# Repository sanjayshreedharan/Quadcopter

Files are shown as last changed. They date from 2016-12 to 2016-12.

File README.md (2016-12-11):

# Quadcopter
An Indigenous Low cost Autopilot System for a Quadcopter using Arduino UNO/ FPGA.
 
This project endeavours to design a low cost indigenous auto-pilot system for a quadcopter using the Arduino UNO. This tutorial majorly deals only with the design and deployment of the autopilot system and we assume that you already have the frame, motors, ESC’s and the Lipo Batteries in place. This project also includes the PCB schematic on which our firmware is run.  

# Video

DEMO Video (http://www.youtube.com/watch?v=Ulz9EfYzbyA)

# Deployment Instructions
The frame can either be designed or it can be bought. For speedy development, if you don't have much time in your hands I would suggest to go with buying one. 

We obviously designed our own frame and since frame design and construction as such is a huge task, I would follow up with a tutorial for those of you who wish to design your own frames.

After the frame is ready, the next would be to get the motors, ESC’s, propellers and the power supply in place.The rating of the motors, ESC’s and power supply depends on the size of the frame and the pay-load capacity of the quadcopter. 

For autopilot, a 9DOF IMU (Inertial measurements unit), which consists of an accelerometer, gyroscope and a magnetometer is required. For wireless communication, Bluetooth or RC would do the job. We used the Bluetooth as we would be able to keep a watch on the state of the quadcopter through the serial monitor and also send commands. If flying low-heights and debugging is your requirement, go with bluetooth. For those of you who wish to fly great heights, use a RC module. 

The MPU6050 (6 DOF IMU with accelerometer and gyroscope) and HMC5883L(Magnetometer) was combined to give the quadcopter 9 degrees of freedom. The HC-06 module was used as bluetooth.

A custom Arduino UNO shield was designed for the purpose of a quadcopter. The schematic and the board design is available. So, if you know know how to make a PCB, you can make the shield with the MPU6050, HMC5883L and HC-06 on it and it would fit perfectly on top of the UNO.  

If making PCB is not your piece of cake, I would suggest you to connect the sensors with jumper wires. Make sure the connections, that you have made are reliable, if they are not this might pose a serious problem when the quadcopter is on the go.

After this is done, download the code and fuse it into your Arduino UNO.

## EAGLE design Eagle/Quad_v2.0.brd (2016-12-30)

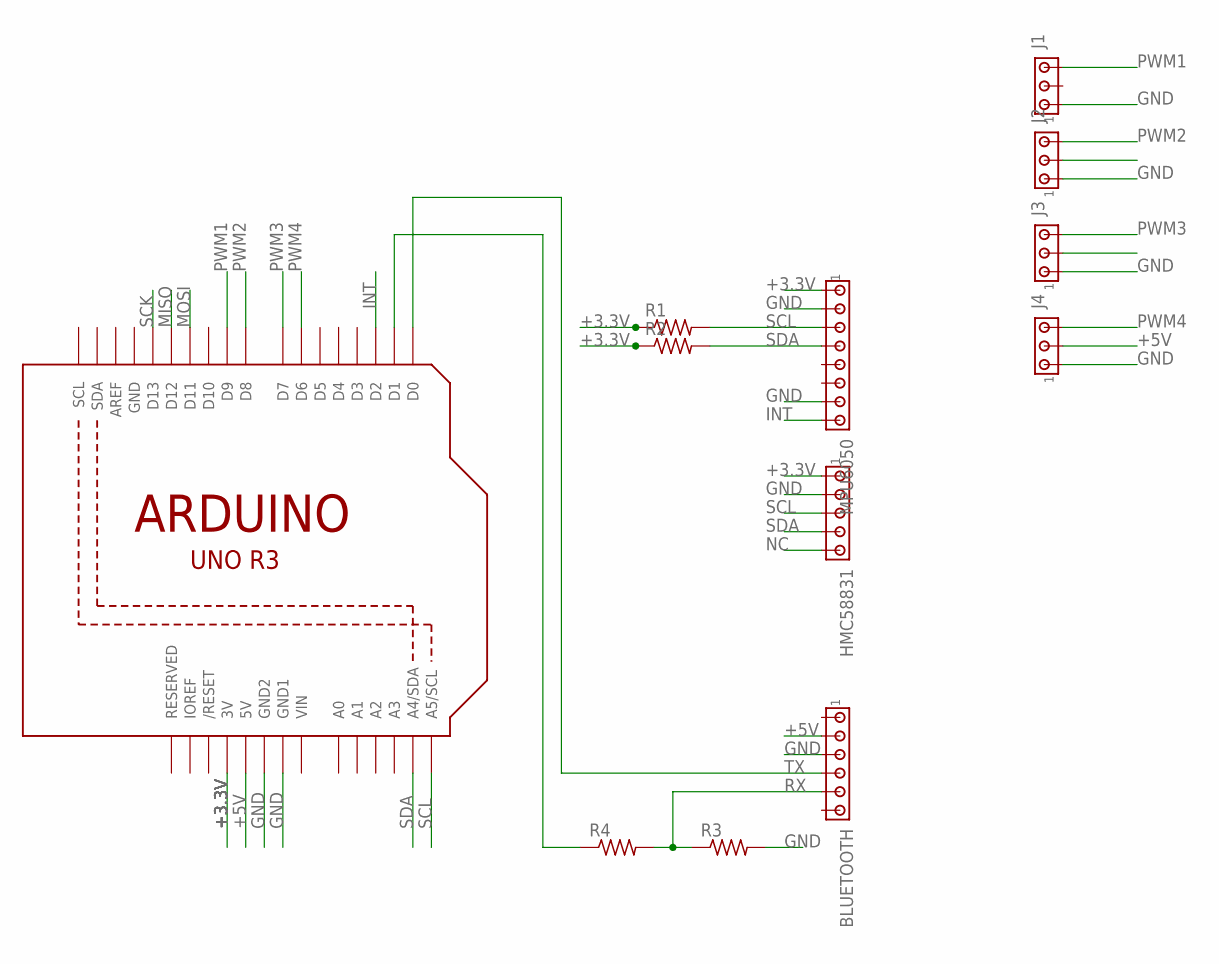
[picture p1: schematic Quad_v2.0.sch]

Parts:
BLUETOOTH: MTA06-100; 10X06MTA
HMC58831: MTA05-100; 10X05MTA
J1, J2, J3, J4: MTA03-100; 10X03MTA
MPU6050: MTA08-100; 10X08MTA
R1, R2, R3, R4: R-US_0204/7; 0204/7
U1: ARDUINOR3-DIMENSION; ARDUINOR3

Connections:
+3.3V: HMC58831.1, MPU6050.1, R1.1, R2.1, U1.3V
+5V: BLUETOOTH.5 (2), J4.2, U1.5V
GND: BLUETOOTH.4 (3), HMC58831.2, J1.1, J2.1, J3.1, J4.1, MPU6050.2, MPU6050.7, R3.2, U1.GND, U1.GND1, U1.GND2
INT: MPU6050.8, U1.D2
MISO: U1.D12
MOSI: U1.D11
unnamed: R4.1, U1.D1
NC: HMC58831.5
PWM1: J1.3, U1.D9
PWM2: J2.3, U1.D8
PWM3: J3.3, U1.D7
PWM4: J4.3, U1.D6
RX: BLUETOOTH.2 (5), R3.1, R4.2
SCK: U1.D13
SCL: HMC58831.3, MPU6050.3, R1.2, U1.A5 (A5/SCL)
SDA: HMC58831.4, MPU6050.4, R2.2, U1.A4 (A4/SDA)
TX: BLUETOOTH.3 (4), U1.D0
VIN: U1.VIN

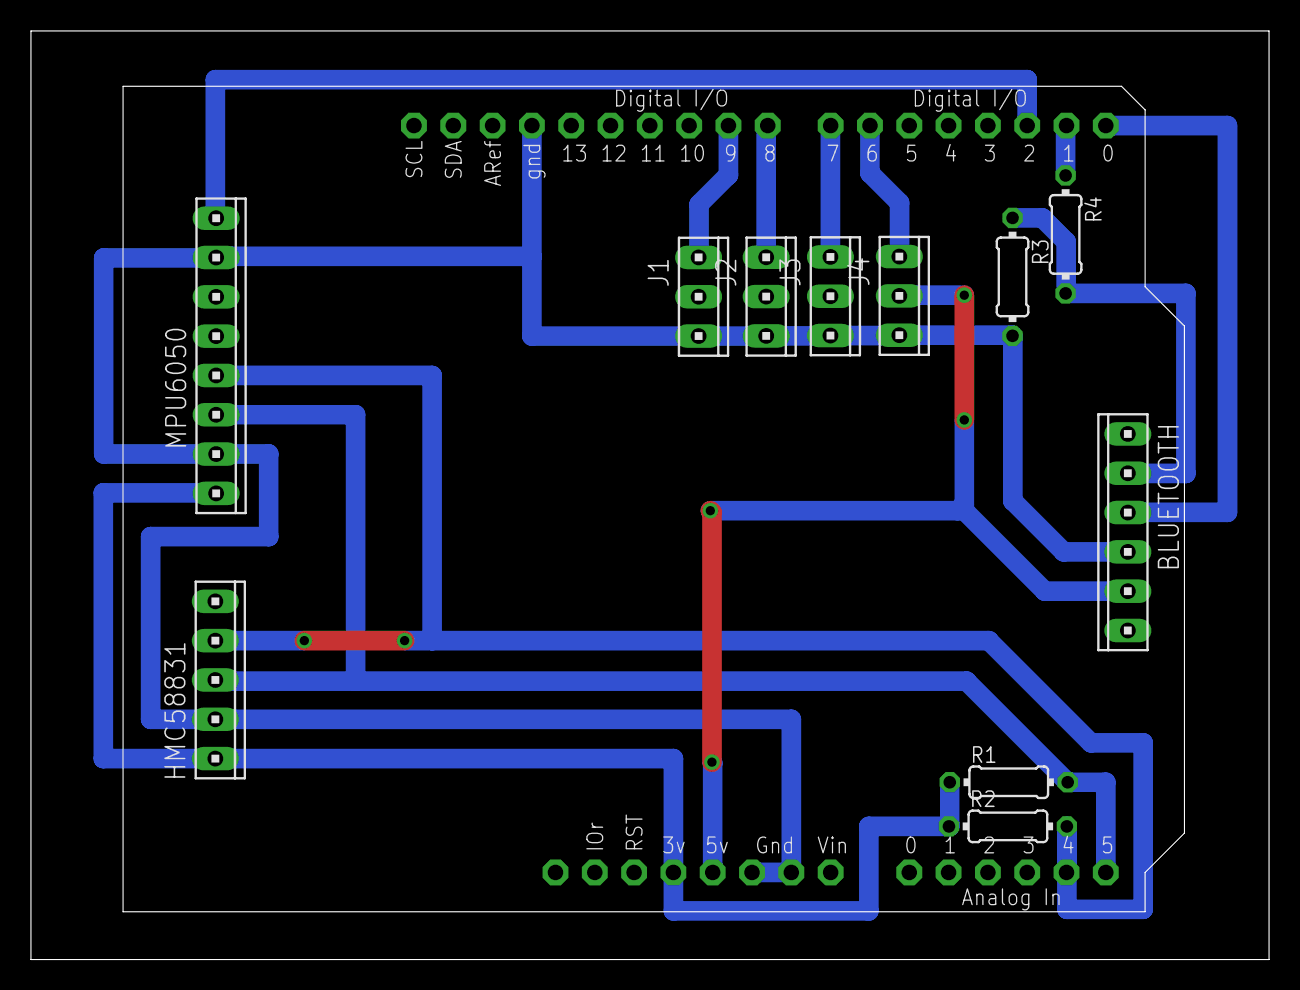
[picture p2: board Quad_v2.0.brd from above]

Board: 2 copper layers, 80.0 x 60.0 mm, 12 parts (0 on the bottom side), 13 nets.

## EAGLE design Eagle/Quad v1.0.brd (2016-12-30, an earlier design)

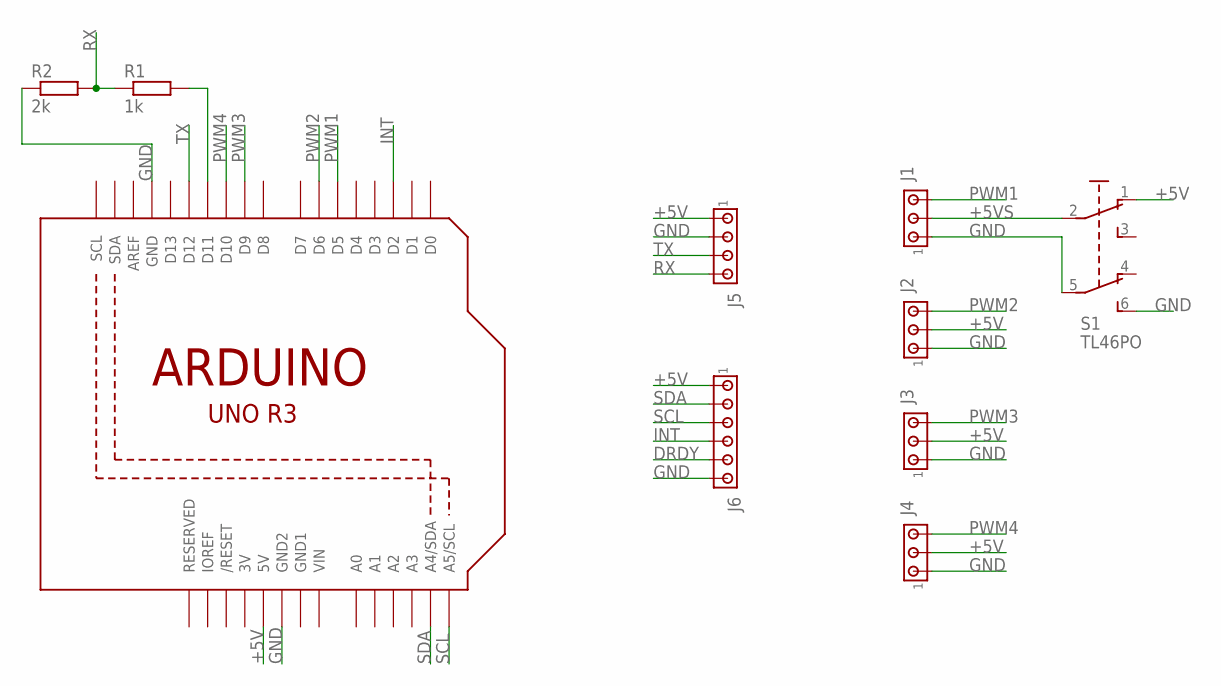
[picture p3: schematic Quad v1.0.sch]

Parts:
J1, J2, J3, J4: MTA03-100; 10X03MTA
J5: MTA04-100; 10X04MTA
J6: MTA06-100; 10X06MTA
R1: 1k; 0204/7
R2: 2k; 0204/7
S1: TL46PO; TL4XPO
U1: ARDUINOR3-DIMENSION; ARDUINOR3

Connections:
3V: U1.3V
+5V: J2.2, J3.2, J4.2, J5.1, J6.6 (1), S1.1 (O), U1.5V
+5VS: J1.2, S1.2
DRDY: J6.2 (5)
GND: J1.1, J2.1, J3.1, J4.1, J5.2, J6.1 (6), R2.1, S1.5 (P1), S1.6 (S1), U1.GND, U1.GND2
GND1: U1.GND1
INT: J6.3 (4), U1.D2
unnamed: R1.2, U1.D11
PWM1: J1.3, U1.D5
PWM2: J2.3, U1.D6
PWM3: J3.3, U1.D9
PWM4: J4.3, U1.D10
RX: J5.4, R1.1, R2.2
SCL: J6.4 (3), U1.A5 (A5/SCL)
SDA: J6.5 (2), U1.A4 (A4/SDA)
TX: J5.3, U1.D12
VIN: U1.VIN

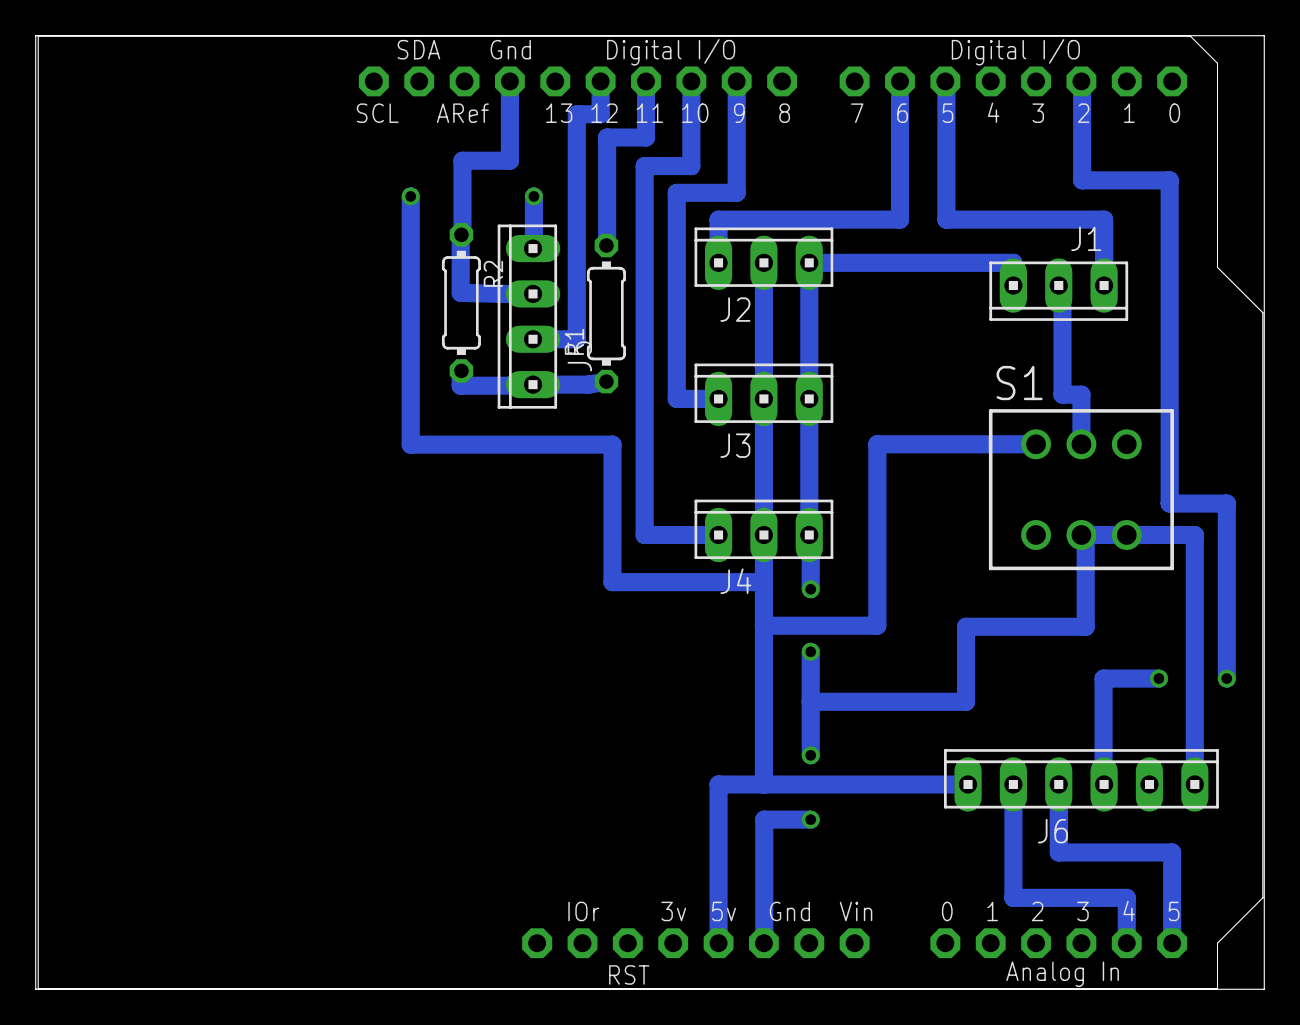
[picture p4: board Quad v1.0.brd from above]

Board: 2 copper layers, 68.8 x 53.4 mm, 10 parts (0 on the bottom side), 13 nets.

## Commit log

2016-12-30 Add v1.0 Eagle CAD PCB files
    [Quad v1.0.brd, Quad v1.0.sch]
2016-12-30 Update to v2.0 Eagle CAD PCB Files
    [Quad_v2.0.brd, Quad_v2.0.sch]
